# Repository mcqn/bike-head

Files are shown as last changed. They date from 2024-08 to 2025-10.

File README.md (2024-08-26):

# Bike Head

Making your bike more fun (if that's possible) by giving it a head.

A laser-cut template to make a cardboard head to mount on the handlebars of your bike.  Then customize it with craft supplies or LEDs and a Microbit.

## Notes on creating the design

In FreeCAD...

1. Created a sketch of the side profile
1. Made a copy of that sketch
1. Opened the attachment editor for each sketch and offset one by 75mm on Z and -8&deg; rotation around Y, and the other by -75 and 8&deg;
1. Then in the Surface workbench, filled in each side to give two surfaces
1. And then repeatedly used the boundary curve to create each connecting surface between the sides
1. In the Draft workbench I selected all the centre, connecting surfaces and upgraded them to a shell
1. Then in the Mesh workbench I could convert the shell to a mesh and then unwrap it to get the net for those shapes
1. The convert to mesh and unwrap process was repeated for the two sides
1. Then used Transform to orient the sides to broadly the right place
1. And in the Draft workbench rotated and moved the sides to be offset by 3mm from the long face
   1. Selected each end of the corresponding lines in the side and the centre piece which are to be lined up, and noted their `x` and `y` coordinates.
   1. Worked out the angle of the centre piece line with respect to `y` (in this instance) - `theta`, with `tan^-1(x_diff/y_diff)`
   1. Worked out new coordinates for corresponding point in the side with `x_offset` being `3 * sin(90-theta)` and `y_offset` being `3* cos(90-theta)`
   1. Work out the distance to move the side so it ends up at the right place.  Use the Placement in the side's properties to nudge it
   1. Rotate the side to line up parallel to the corresponding line in the centre.  I ended up eyeballing this rather than calculating it
   1. Repeat for the other side

## Game Notes

### Pacman

### Tick

1. Start up and loop until someone is chosen or a timeout happens:
   1. Transmit your ID
   1. Wait to receive someone-else's ID
   1. Vote on who should be `it`?
1. If it was a timeout, assume someone else is `it` and proceed

1. To begin with, use a button press to select someone as `it`
1. Loop:
   1. If I'm `it`:
      1. Light LED
      1. Broadcast our ID
      1. Listen for a broadcast
      1. If a request to be `it` is received, send a confirmation of passing on
   1. If not `it`:
      1. Turn off LED
      1. Listen for a broadcast
      1. If one found, reply with a request to be `it`
      1. If it's a confirmation of `it`, you're `it`, count down from 5 before looping round

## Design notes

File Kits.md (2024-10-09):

# Kits

## Base Learn to Solder Kit

### You will need

* A soldering iron and some solder
* Wire cutters
* Small Philips (cross-head) screwdriver
* 2 AA batteries (or if you're using a Microbit, a USB power bank would be another option)
* (Optional, but recommended) Microbit

### Parts

| Quantity | Part |
|---|---|
| 1  | [Microbit LED driver PCB](Microbit-LED-Driver) |
| 3  | MOSFET |
| 6  | 1206 330(?) ohm resistors |
| 3  | Screw terminals |
| 1  | 2xAA battery holder
| 5  | M4 x 20mm bolt |
| 10 | M4 nut |
| 1  | 30cm LED noodle |
| 2  | 15cm LED noodle |
| 1  | Cardboard bike head |

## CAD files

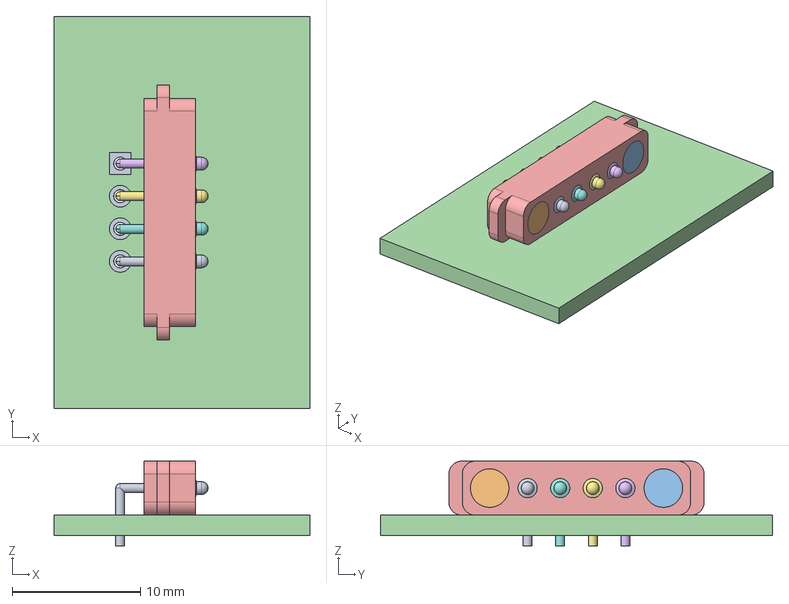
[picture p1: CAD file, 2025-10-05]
NoodleDriver/MagneticPogoPinConnector.FCStd
19.9 x 30.6 x 6.60 mm
topPads
btmPads
TH-Drills
PCB
Shroud
Pin
PinClone002
PinClone003
PinClone004
Magnet
MagnetClone006

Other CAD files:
bike-head.FCStd

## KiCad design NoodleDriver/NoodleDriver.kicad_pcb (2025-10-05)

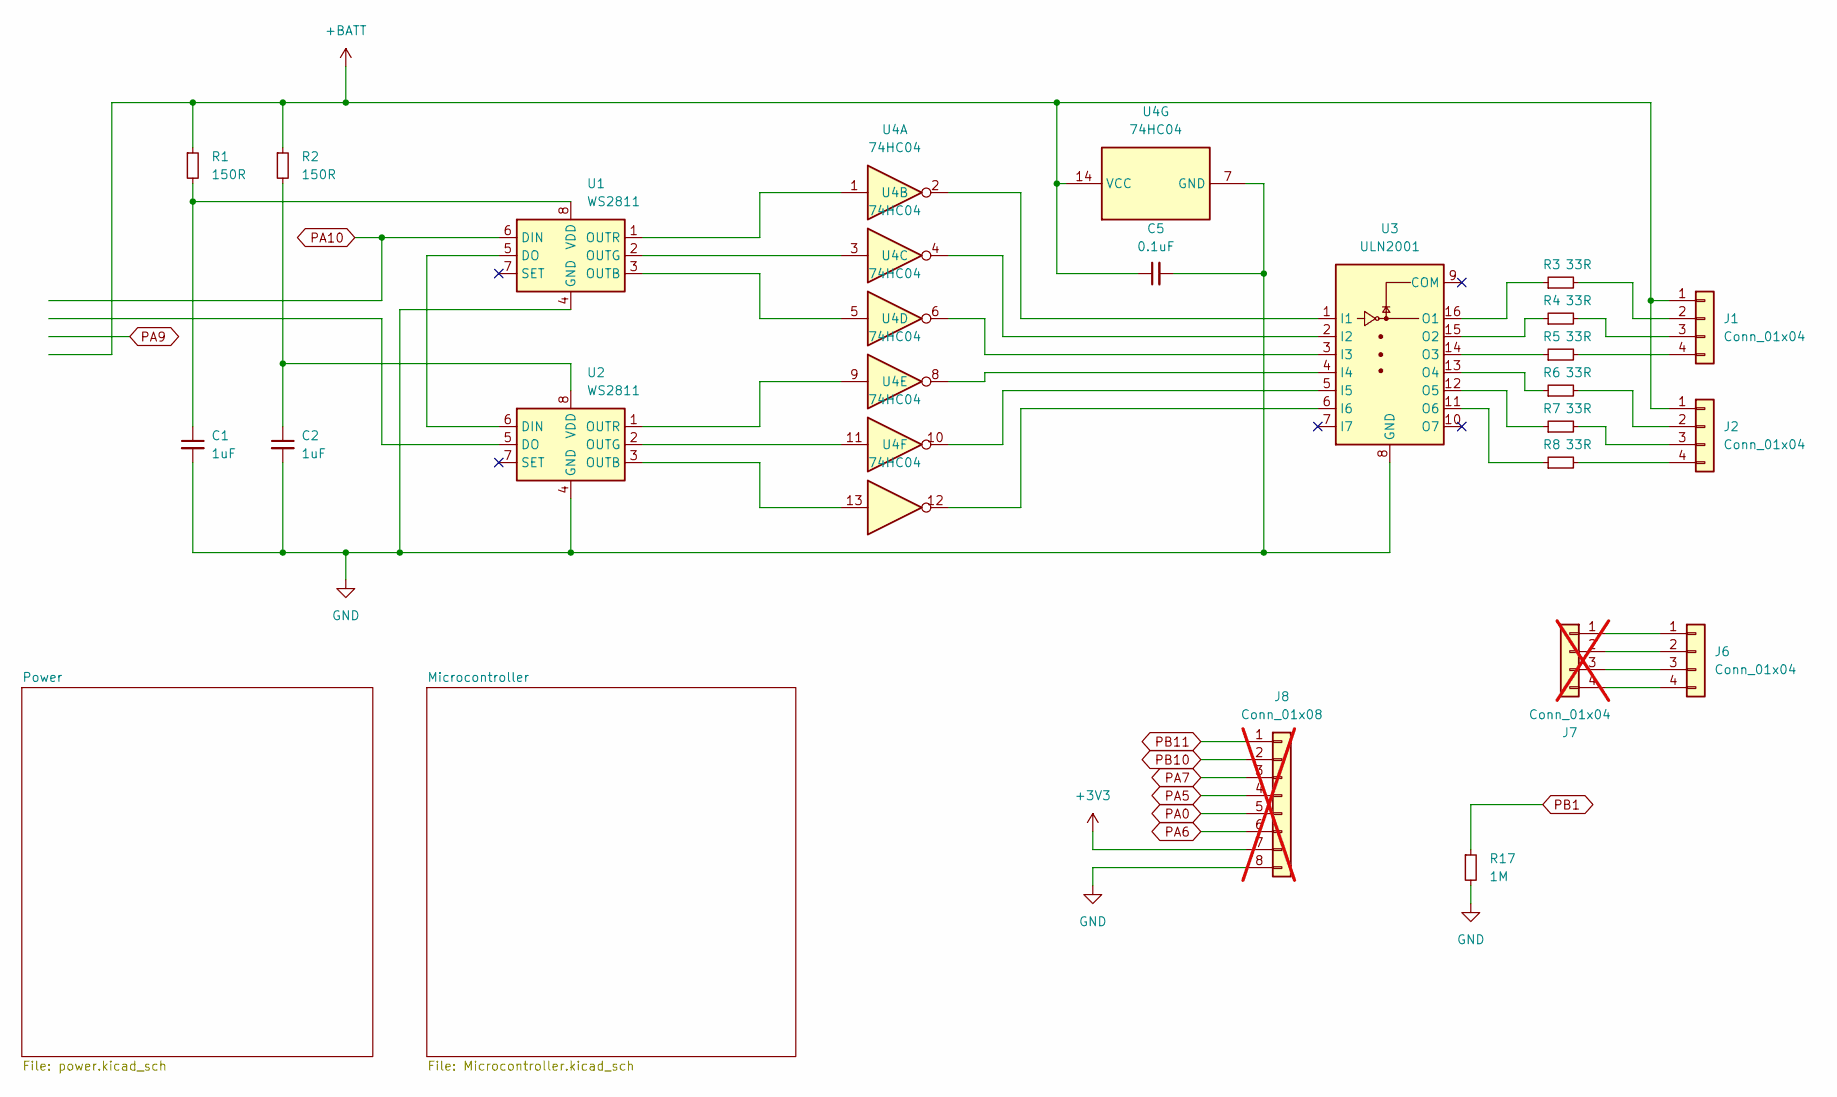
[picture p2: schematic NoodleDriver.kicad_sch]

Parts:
C1, C2: 1uF; C_0402_1005Metric; LCSC C14445
C5: 0.1uF; C_0402_1005Metric; LCSC C77020
J1, J2, J6: Conn_01x04; MagneticPogoPinConnector_1x04_P2.54mm_Horizontal
J7: Conn_01x04; PinSocket_1x04_P2.54mm_Vertical; not fitted
J8: Conn_01x08; PinSocket_1x08_P2.54mm_Vertical; not fitted
R1, R2: 150R; R_0402_1005Metric; LCSC C138054
R3, R4, R5, R6, R7, R8: 33R; R_0603_1608Metric
R17: 1M; R_0402_1005Metric
U1, U2: WS2811; SOP-8_3.76x4.96mm_P1.27mm; LCSC C114581
U3: ULN2001; SOIC-16_3.9x9.9mm_P1.27mm; LCSC C165966
U4: 74HC04; SOIC-14_3.9x8.7mm_P1.27mm; LCSC C86613

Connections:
+3V3: J8.7; also elsewhere on the board
+BATT: C5.1, J1.1, J2.1, R1.1, R2.1, U4.14 (VCC); also elsewhere on the board
GND: C1.2, C2.2, C5.2, J8.8, R17.2, U1.4 (GND), U2.4 (GND), U3.8 (GND), U4.7 (GND); also elsewhere on the board
unnamed: J1.2, R3.2
unnamed: J1.3, R4.2
unnamed: J1.4, R5.2
unnamed: J2.2, R6.2
unnamed: J2.3, R7.2
unnamed: J2.4, R8.2
unnamed: J6.1, J7.1
unnamed: J6.2, J7.2
unnamed: J6.3, J7.3
unnamed: J6.4, J7.4
unnamed: U1.5 (DO), U2.6 (DIN)
unnamed: U1.3 (OUTB), U4.5
unnamed: U1.2 (OUTG), U4.3
unnamed: U1.1 (OUTR), U4.1
unnamed: C1.1, R1.2, U1.8 (VDD)
unnamed: U2.3 (OUTB), U4.13
unnamed: U2.2 (OUTG), U4.11
unnamed: U2.1 (OUTR), U4.9
unnamed: C2.1, R2.2, U2.8 (VDD)
unnamed: U3.1 (I1), U4.2
unnamed: U3.2 (I2), U4.4
unnamed: U3.3 (I3), U4.6
unnamed: U3.4 (I4), U4.8
unnamed: U3.5 (I5), U4.10
unnamed: U3.6 (I6), U4.12
unnamed: R3.1, U3.16 (O1)
unnamed: R4.1, U3.15 (O2)
unnamed: R5.1, U3.14 (O3)
unnamed: R6.1, U3.13 (O4)
unnamed: R7.1, U3.12 (O5)
unnamed: R8.1, U3.11 (O6)
PA0: J8.5; also elsewhere on the board
PA5: J8.4; also elsewhere on the board
PA6: J8.6; also elsewhere on the board
PA7: J8.3; also elsewhere on the board
PA10: U1.6 (DIN); also elsewhere on the board
PB1: R17.1; also elsewhere on the board
PB10: J8.2; also elsewhere on the board
PB11: J8.1; also elsewhere on the board

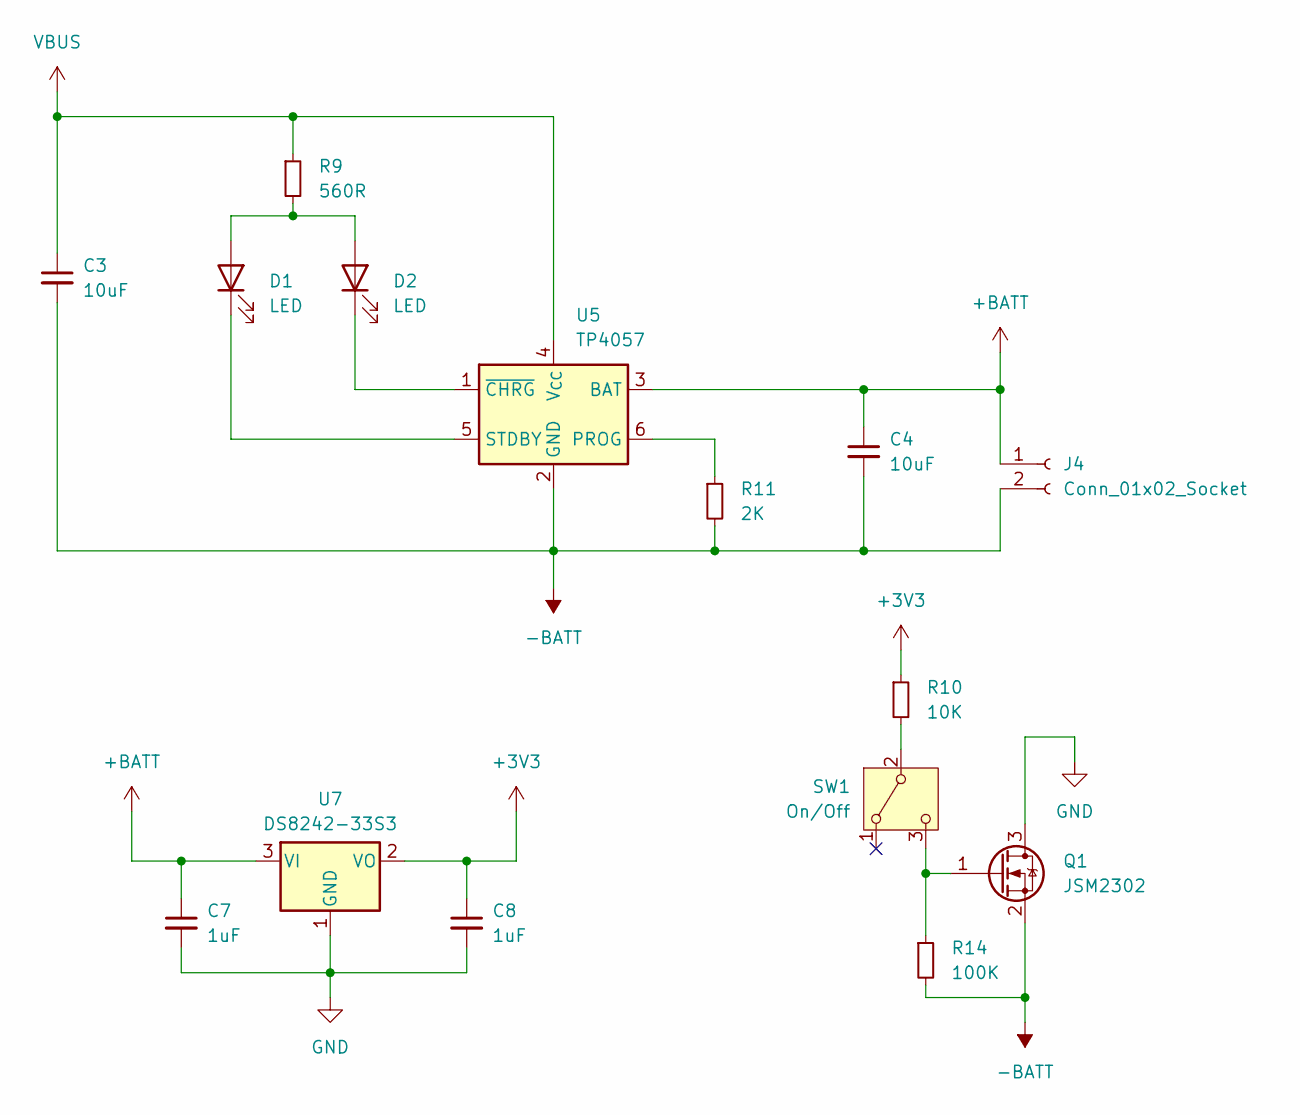
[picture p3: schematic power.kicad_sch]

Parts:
C3, C4: 10uF; C_0603_1608Metric; LCSC C6119842
C7, C8: 1uF; C_0402_1005Metric; LCSC C14445
D1, D2: LED; LED_0402_1005Metric
J4: Conn_01x02_Socket; JST_PH_B2B-PH-SM4-TB_1x02-1MP_P2.00mm_Vertical
Q1: JSM2302; SOT-23; LCSC C916403
R9: 560R; R_0402_1005Metric; LCSC C163460
R10: 10K; R_0402_1005Metric
R11: 2K; R_0402_1005Metric; LCSC C4109
R14: 100K; R_0402_1005Metric
SW1: On/Off; SW_Slide_SPDT_Angled_CK_OS102011MA1Q; Farnell 1201431
U5: TP4057; TSOT-23-6; LCSC C725791
U7: DS8242-33S3; SOT-23-3; LCSC C5884132

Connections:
+3V3: C8.1, R10.1, U7.2 (VO); also elsewhere on the board
+BATT: C4.1, C7.1, J4.1, U5.3 (BAT), U7.3 (VI); also elsewhere on the board
-BATT: C3.2, C4.2, J4.2, Q1.2 (S), R11.2, R14.2, U5.2 (GND); also elsewhere on the board
GND: C7.2, C8.2, Q1.3 (D), U7.1 (GND); also elsewhere on the board
unnamed: D1.2 (A), D2.2 (A), R9.2
unnamed: D1.1 (K), U5.5 (STDBY)
unnamed: D2.1 (K), U5.1 (~CHRG)
unnamed: Q1.1 (G), R14.1, SW1.3 (C)
unnamed: R10.2, SW1.2 (B)
unnamed: R11.1, U5.6 (PROG)
VBUS: C3.1, R9.1, U5.4 (V_{CC}); also elsewhere on the board

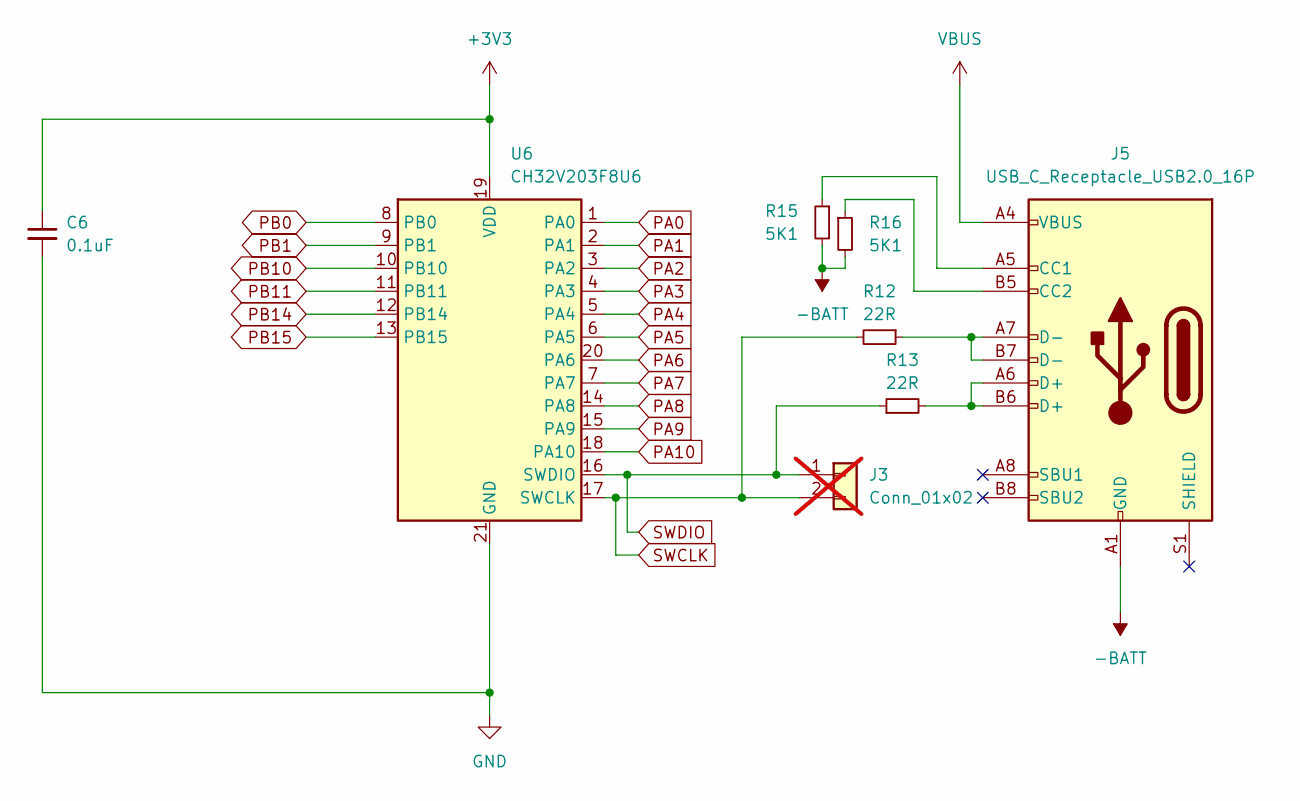
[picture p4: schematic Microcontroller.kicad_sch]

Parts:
C6: 0.1uF; C_0402_1005Metric; LCSC C77020
J3: Conn_01x02; PinSocket_1x02_P2.54mm_Vertical; not fitted
J5: USB_C_Receptacle_USB2.0_16P; USB_C_PADDLE
R12, R13: 22R; R_0402_1005Metric; LCSC C114765
R15, R16: 5K1; R_0402_1005Metric; LCSC C25905
U6: CH32V203F8U6; QFN-20-1EP_3x3mm_P0.45mm_EP1.6x1.6mm; LCSC C7570477

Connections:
+3V3: C6.1, U6.19 (VDD); also elsewhere on the board
-BATT: J5.A1 (GND), J5.A12 (GND), J5.B1 (GND), J5.B12 (GND), R15.2, R16.2; also elsewhere on the board
GND: C6.2, U6.21 (GND); also elsewhere on the board
unnamed: J5.A5 (CC1), R15.1
unnamed: J5.B5 (CC2), R16.1
unnamed: J5.A6 (D+), J5.B6 (D+), R13.2
unnamed: J5.A7 (D-), J5.B7 (D-), R12.1
PA0: U6.1 (PA0); also elsewhere on the board
PA1: U6.2 (PA1)
PA2: U6.3 (PA2)
PA3: U6.4 (PA3)
PA4: U6.5 (PA4)
PA5: U6.6 (PA5); also elsewhere on the board
PA6: U6.20 (PA6); also elsewhere on the board
PA7: U6.7 (PA7); also elsewhere on the board
PA8: U6.14 (PA8)
PA9: U6.15 (PA9)
PA10: U6.18 (PA10); also elsewhere on the board
PB0: U6.8 (PB0)
PB1: U6.9 (PB1); also elsewhere on the board
PB10: U6.10 (PB10); also elsewhere on the board
PB11: U6.11 (PB11); also elsewhere on the board
PB14: U6.12 (PB14)
PB15: U6.13 (PB15)
SWCLK: J3.2, R12.2, U6.17 (SWCLK)
SWDIO: J3.1, R13.1, U6.16 (SWDIO)
VBUS: J5.A4 (VBUS), J5.A9 (VBUS), J5.B4 (VBUS), J5.B9 (VBUS); also elsewhere on the board

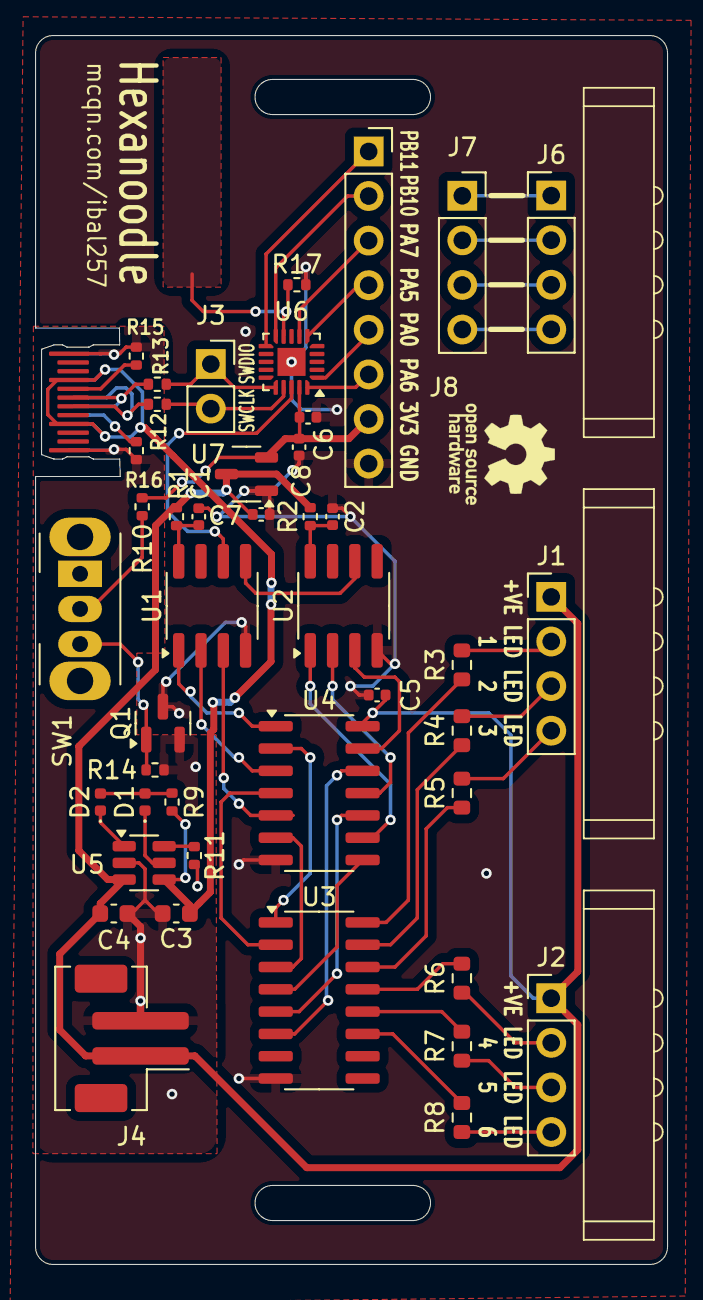
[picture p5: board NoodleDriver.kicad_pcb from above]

Board: 2 copper layers, 36.0 x 70.0 mm, 44 parts (0 on the bottom side), 56 nets.

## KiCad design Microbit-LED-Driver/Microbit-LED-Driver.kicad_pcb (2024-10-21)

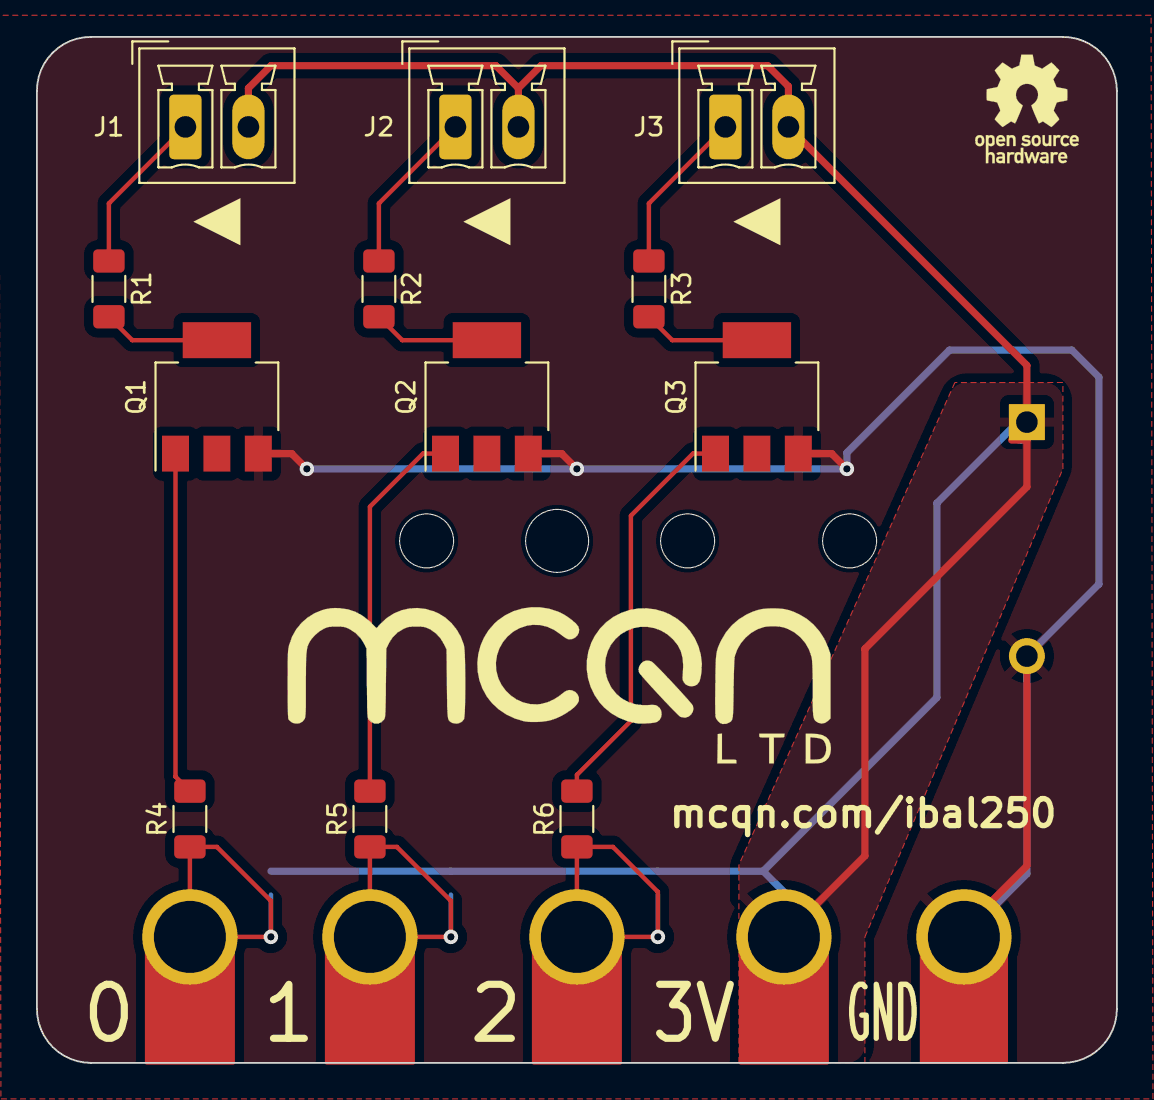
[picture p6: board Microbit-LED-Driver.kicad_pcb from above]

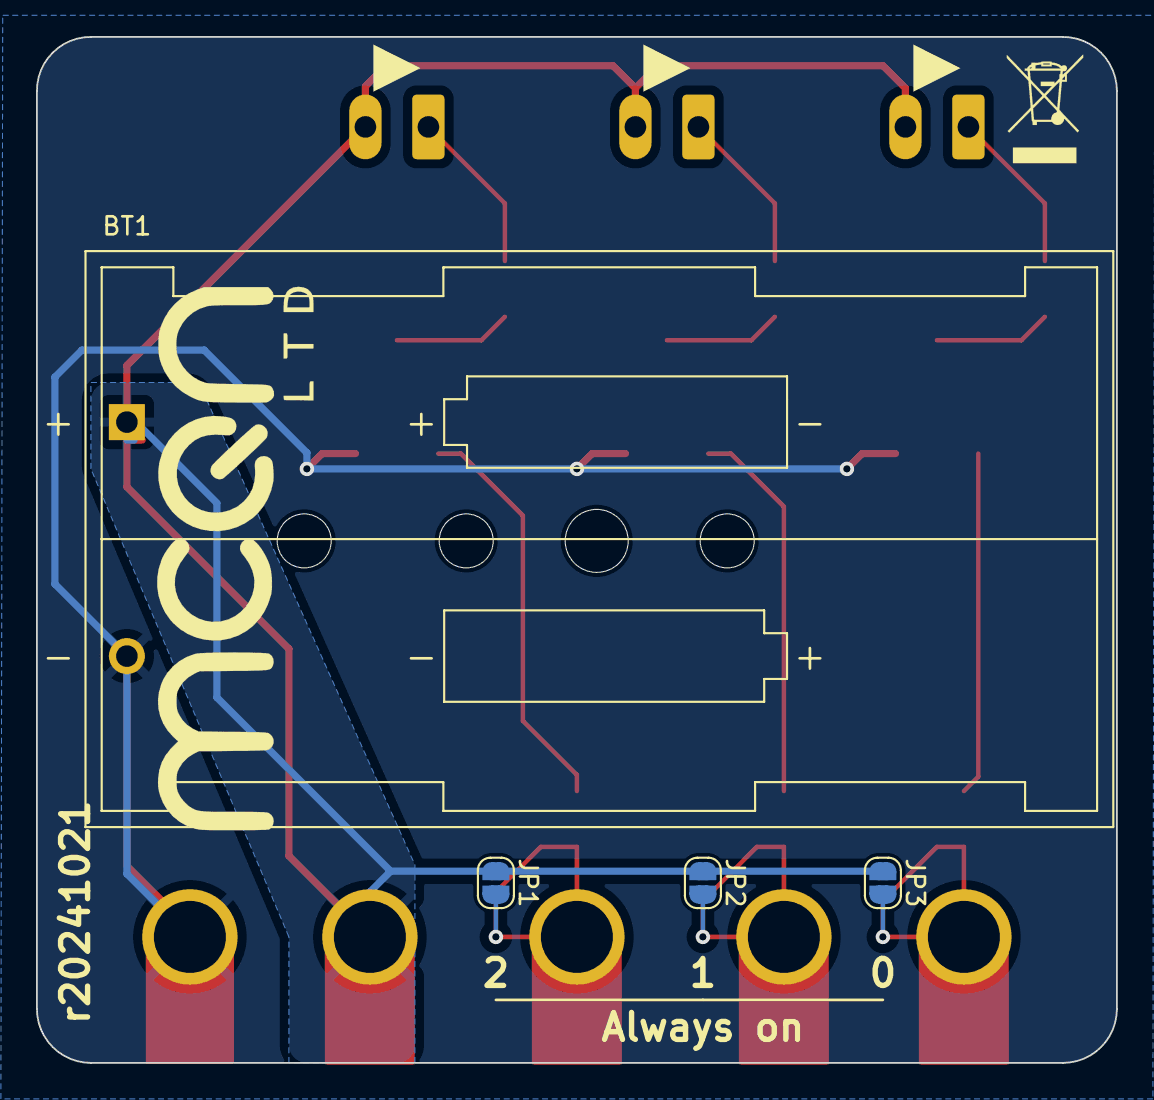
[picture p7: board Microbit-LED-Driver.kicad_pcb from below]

Board: 2 copper layers, 60.0 x 57.0 mm, 17 parts (4 on the bottom side), 14 nets.

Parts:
BT1: Battery; BatteryHolder_Multicomp_MP000325_2xAA
J1, J2, J3: Conn_01x02_Socket; PhoenixContact_MCV_1,5_2-G-3.5_1x02_P3.50mm_Vertical
J4: Microbit Bolt Connector
JP1, JP2, JP3: SolderJumper_2_Open; SolderJumper-2_P1.3mm_Open_RoundedPad1.0x1.5mm
Q1, Q2, Q3: BCP56; SOT-223-3_TabPin2
R1, R2, R3, R4, R5, R6: R_Small; R_1206_3216Metric_Pad1.30x1.75mm_HandSolder

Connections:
+3V0: BT1.1 (+), J1.2, J2.2, J3.2, J4.3 (3V), JP1.1 (A), JP2.1 (A), JP3.1 (A)
GND: BT1.2 (-), J4.4 (GND), Q1.3 (E), Q2.3 (E), Q3.3 (E)
unnamed: J1.1, R1.1
unnamed: J2.1, R2.1
unnamed: J3.1, R3.1
unnamed: J4.2, JP1.2 (B), R6.1
unnamed: J4.1, JP2.2 (B), R5.1
unnamed: J4.0, JP3.2 (B), R4.1
unnamed: Q1.1 (B), R4.2
unnamed: Q1.2 (C), R1.2
unnamed: Q2.1 (B), R5.2
unnamed: Q2.2 (C), R2.2
unnamed: Q3.1 (B), R6.2
unnamed: Q3.2 (C), R3.2

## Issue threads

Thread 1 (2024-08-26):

Test fitment onto a variety of handlebar types

amcewen, 2024-08-26:
So far it's only been tested with my handlebars.  Would be good to check with more, particularly mountain bike, BMX and kids bike sizes.

amcewen, 2024-08-26:
For my handlebars it would be useful to have the squared-off cut-out be ~5mm wider and ~15mm higher.

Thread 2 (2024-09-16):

Build a PCB for easier LED attachment/driving

amcewen, 2024-09-16:
We should have a PCB that bolts to the Microbit and contains the transistors and some screw terminals to let us easily hook up three LED noodles to the Microbit.

It should:
* Have screw terminals for the LED attachment
* Use easy-to-solder surface-mount components so it can be both readily manufactured and act as a beginners SMD soldering kit
* Take a battery to provide power to the LEDs and the Microbit (2xAA is probably best - it'll last a bit longer than the 2xAAA that are common with the Microbit)
* Have options to just run the LEDs always on, so it can be used without the Microbit

amcewen, 2024-09-16:
10 test boards ordered from JLC today.  Didn't bother with a stencil as that'll let us test the hand-solderability :grinning:

amcewen, 2024-09-16:
I've ordered the parts for the 10 boards, apart from the resistors as there are a load of 1206 resistors of various values already in DoES.  We'll also need some nuts and bolts for fastening them to the microbits, and the LED noodles!

amcewen, 2024-09-23:
PCBs arrived this afternoon and seem (mostly) okay.  Will spin out separate issues to cover particulars of bugs or remaining tasks.

Closed 2024-09-23.

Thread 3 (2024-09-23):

Battery holder clashes with terminal blocks if they're both mounted on the rear of the PCB

amcewen, 2024-09-23:
Testing one of the fabbed boards, the blue terminal blocks (the green ones are a little bit better, but not perfect) foul the battery holder if they're mounted on the rear of the board.

Mounting them on the rear makes more sense to then mount that board underneath the cardboard, so that's the more likely placement.

amcewen, 2024-10-16:
Having a bit more room for the nuts on the bolted connection would also be useful, so I think nudging the battery holder a bit further from the connector too would be useful

Closed 2024-10-21.

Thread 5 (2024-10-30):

Design a basestation

amcewen, 2024-10-30:
For some of the games it would be nice to have stationary "basestations" that you had to visit.

Maybe they could be a My Bike's Got LED board with some neopixels, and possibly inside a length of white plastic waste pipe?  PEX pipe is a nice diffuser, although the [waste pipe I can find right now seems to be ABS](https://www.screwfix.com/p/floplast-solvent-weld-pipes-white-50mm-x-3m/88188) (50mm ID).  Maybe that is still translucent enough?

It would be a useful product system to tap into, as it's obviously waterproof, and there are fitments like [this screw-on end-cap](https://www.screwfix.com/p/floplast-solvent-weld-access-plug-white-50mm/72586) that would make accessing batteries, etc. easier.

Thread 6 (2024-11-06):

Can we communicte using the Microbit radio format from other devices?

huffeec, 2024-11-06:
Link to Lancaster Uni C/C++ Microbit code
[micro:bit runtime](https://lancaster-university.github.io/microbit-docs/)

huffeec, 2025-01-22:
The espressif [Nimble](https://docs.espressif.com/projects/esp-idf/en/stable/esp32/api-reference/bluetooth/nimble/index.html) BLE implementation is based on [Apache nimBLE ](https://mynewt.apache.org/latest/network/index.html)

[myNewt nimBLE](https://github.com/apache/mynewt-nimble) is available for nrf 51 devices

The [Proximity sensor example](https://github.com/espressif/esp-idf/tree/master/examples/bluetooth/nimble/ble_proximity_sensor/proximity_sensor_cent) appears to offer some of the functionality we need.

Alternatively [this library](https://github.com/masuidrive/esp-nimble-nordic-uart/tree/main/components/nimble-nordic-uart) claims to be able to communicate with Nordic UART over nimBLE but would need to unpack/redefine the [microbit bluetooth spec](https://lancaster-university.github.io/microbit-docs/resources/bluetooth/bluetooth_profile.html)

[https://studio.keil.arm.com/](https://studio.keil.arm.com/) allows webUSB programming of microbits.

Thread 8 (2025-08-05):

Use RGB LED driver chip to open up driving more LEDs?

amcewen, 2025-08-05:
The limit of three LEDs due to the croc-clip pin-out of the Microbit is annoying.  I realised today that we could probably use the driver chips from the ubiquitous RGB LEDs, and then we'll just need a single data line to drive as many LEDs as make sense.

LCSC has the [WS2811 driver ICs](https://www.lcsc.com/product-detail/C114581.html) in SOP-8 form for about 3p.  They can only source ~16.5mA of current though, so to drive a full noodle we'd probably want something to increase that.

amcewen, 2025-10-05:
Went with a `TP4057` charger as Kicad had the component for that; added a `CH32V203` microcontroller; and ditched the micro:bit connector as it doesn't need it if there's a processor on-board (and that made the board smaller)

Trying out a component-less USB-C connector, which requires 0.6mm PCB with ENIG finish.  The ENIG finish is an extra $16, and black soldermask (feels sensible for wearable options to make them less obvious) is an additional $33.

Have ordered 5 green prototype boards.

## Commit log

2024-08-26 Initial version for testing, and adding the licence.
    [bike-head.FCStd]
2024-09-16 First pass of LED driver PCB, as sent for fabbing. Part of #2
    [Microbit-LED-Driver.kicad_pcb, Microbit-LED-Driver.kicad_sch]
2024-10-21 Nugde position of screw terminals and battery holder so they shouldn't clash. Fixes #3
    [Microbit-LED-Driver.kicad_pcb, Microbit-LED-Driver.kicad_sch]
2025-08-21 First sketch of design using WS2811 drivers to drive more noodles. Part of #8
    [NoodleDriver.kicad_pcb, NoodleDriver.kicad_sch]
2025-09-17 Add a microcontroller, and regulator and USB-C connector. Checkin before I try swapping out the microbit and 0.1" headers. Part of #8
    [Microcontroller.kicad_sch, NoodleDriver.kicad_pcb, NoodleDriver.kicad_sch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]
2025-09-24 Exclude the USB contacts from the solderpaste layers.
2025-10-05 Final tuning of prototype board, which we've ordered a handful of prototypes to be fabbed. Part of #8
    [MagneticPogoPinConnector.FCStd, Microcontroller.kicad_sch, NoodleDriver.kicad_pcb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]
